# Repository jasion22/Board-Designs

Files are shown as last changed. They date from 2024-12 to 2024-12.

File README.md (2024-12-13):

# Gateway_Docking_Station
This project focuses on creating a gateway system that connects remote and host networks using a Raspberry Pi 3B+ and an RAK 833 (a LoRaWAN concentrator). This 

# Getting Started
- Make sure that you have a C1_Node_revb_v1.0.
- Raspberry Pi 3B+.
- RAK 833.

# Prerequisites
Board [Tested]

# Contributing
Instructions coming up soon.

# License
This project is licensed under the MIT License - see the LICENSE.md file for details

# Acknowledgments

# Changelog

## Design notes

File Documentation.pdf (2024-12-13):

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

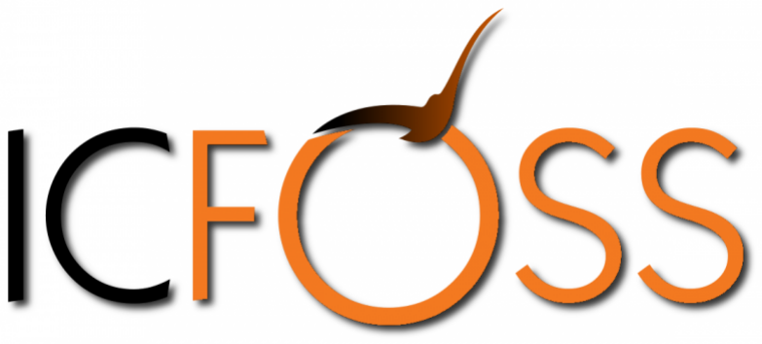
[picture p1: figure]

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

## 1. Summary

Any network has a boundary or a limit, so all communication placed within that network is conducted using the devices attached to it, including switches and routers. If a network node wants to communicate with a node/network that resides outsides of that network or autonomous system, the network will require the services of a gateway, which is familiar with the routing path of other remote networks.
The gateway (or default gateway) is implemented at the boundary of a network to manage all the data communication that is routed internally or externally from that network. Besides routing packets, gateways also possess information about the host network's internal paths and the learned path of dierent remote networks. If a network node wants to communicate with a foreign network, it will pass the data packet to the gateway, which then routes it to the destination using the best possible path.
The designed gateway docking station is implemented for easy installation process and provides voltage protection.

1

## 2. Problem denition and background

With the emergence of smart cities, smart communities and smart homes, the wireless technology has been greatly developed and applied for every research processes. Nowadays, the wireless methods are commonly used, such as GSM, GPRS, WIFI, ZigBee, etc.. LoRa (Long Range) is a spread spectrum modulation technique derived from chrip spread spectrum(CSS) technology and is the rst low-cost implementation of chirp spread spectrum for commercial usage. It was developed by Cycleo of Grenoble, France and acquired by Semtech in 2012, a founding member of the LoRa Alliance. Semtech's LoRa devices and wireless radio frequency technology (LoRa Technology) is a long range, low power wireless chipset that is used in a lot of Internet of Things (IoT) networks worldwide.
LoRaWAN is a protocol designed for creating large-scale public networks; the technology allows for sensors to talk to the internet without 3G or WiFi. Community crowdsourced projects, such as The Things Network, aim to provide access to this technology by deploying gateways globally that others can freely connect to.
We propose a mechanical water metering system through which we gather the readings by the help of reed switch on Low Power Mode and , thus consuming less power . This provides the device to work for years. The purpose is to provide a guide for people to create their own outdoor LoRaWAN Gateway using o-the-shelf components, rather than purchasing a commercial oering. Many of the components used in this design can be substituted for cheaper alternatives.

## 2.1 Literature review

The major issue based on previous versions of the gateways are

- Most of the gateways that are based on IoT does not provide any voltage protection method.
- Second the power is provided externally.
- Third there is no proper plug in design provided.

So by taking all the above mentioned issues we designed a board that works ne with any voltage issues and that can be used in any residential and commercial purpose. This is commonly

2

eective for large scale developments due to the extreme use of communication nowadays. This can provide the clear usage of data communication that can be accessed within a certain kilometers and could be used for many research purposes and equipments.

## 2.2 Reference solution

The main scope of the design is that the module can be retrotted to an enclosure. The proposed system also works in Low Power which provides a better method for energy consumption. The main objectives are:

- The proposed design provides with a crowbar circuit ie mainly used for voltage protection.
- The other challenge was to provide power without any external power plugins directly so by the use of POE (Power Over Ethernet) the board get sucient power and also a buck boost is provided.
- The board design provides with easy plugin connection for modules.

3

## 3. Design

The design of the project is basically the main task. Usually what's a gateway?. A gateway is a data communication device that provides a remote network with connectivity to a host network. A gateway device provides communication to a remote network or an autonomous system that is out of bounds for the host network nodes. Gateways serve as the entry and exit point of a network; all data routed inward or outward must rst pass through and communicate with the gateway in order to use routing paths. Generally, a router is congured to work as a gateway device in computer networks.
The device should be retrotted to the enclosure designed. For the basic needs the design was developed that can be easily plugged in.

## 3.1 Schematic Design

The schematic diagram represents the basic gateway design for Gateway Docking Station. 1 | 2 | 3 | 4 | 5 | 6
1 | 2 | 3 | 4 | 5 | 6 A

BC

D

A

BC

D Date: KiCad E.D.A. kicad 5.1.5+dfsg1-1 Size: A4 | Rev:
Id: 1/1 Title:

File: Daughter_Board.sch Sheet: / ¹ ² C5

10uF PWR_FLAG

+5V GND-power PWR_FLAG

1
2
3
J6Conn_01x03_Female | GND

PWR_FLAG

1 2 C8

10uF | SW1 SW_Push GND

+5V

1 2 C10

0.1uF

+5V

1 2 C4
47uF,5v D2 SMBJ5.0A
F1 MF-MSMF250/X | R1
1K | 0ER³

1 2 C9

0.1uF

1 2 C11

0.1uF GND

D3

BZG05C36-M

1
2

J3

5Vout | GND 1 VO 2 VI 3 U2 AMS1117-3.3

1 2 C3

# 0.1uF VIN 1 OUT 2 GND

3 FB 4 ON/OFF 5 U1
LM2596S-5

1
2

J4

3.3Vout +3.3V

+5V C6

0.1uf | 1 2 | C2
220uF,10V,AVX_TPSB107M010R0400 | F2 MF-MSMF250/X C7
0.1uf 1

10

2
3 | 4
5 | 6
7 | 8
9

J5 Conn_02x05_Odd_Even

1

10
11 | 12
13 | 14
15 | 16
17 | 18
19

2

20
21 | 22
23 | 24
25 | 26
27 | 28
29

3

30
31 | 32
33 | 34
35 | 36
37 | 38
39

4

40

5 | 6
7 | 8
9

J2 PI GPIO Header 1

2

3

J1
Barrel_Jack_Switch-Connector | Mechanical Key NC 1 | NC | 10 NC 11 | NC | 12 NC 13 | NC | 14 GND 15 | NC | 16 GND 17 | GND | 18 NC 19 | +3.3Vaux | 2 NC | 20 GND 21 | RESET | 22 NC 23 | +3.3Vaux | 24 NC 25 | GND | 26 GND 27 | NC | 28 GND 29 | NC 3 | NC | 30 NC 31 | NC | 32 NC 33 | GND | 34 GND 35 | NC | 36 GND 37 | NC | 38 +3.3Aux 39 | GND | 4 GND | 40 +3.3Aux 41 | NC | 42 GND 43 | NC | 44 PCIe_SCK 45 | NC | 46 PCIe_MISO 47 | NC | 48 PCIe_MOSI 49 | NC 5 | GND | 50 PCIe_CSN 51 | +3.3Vaux | 52 NC | 6 NC 7 | NC | 8 GND 9 | U3 RAK833_MPCIE

1 2

3 | Q1TIC106 GND | R² 100E

1 2 C14

0.1uF

1 2 C12

0.1uF

+3.3V D1 MBRS320T3G 1 2 | C1
470uF,40V,AVX_TPS | L1
47uH,L39 | GND

+3.3V

1 2 C13

0.1uF PCIe_MOSI PCIe_MOSI | PCIe_SCK

PCIe_SCK

PCIe_CSN

RESET PCIe_CSN1 | PCIe_MISO

PCIe_MISO

RESET PCIe_CSN1 PCIe_SCK | RESET PCIe_CSN
Vin | Vin PCIe_MOSI PCIe_MISO

Figure 3.1: Schematic Diagram

4

## 3.2 Layout Design

The layout design of the Gateway Docking Station.

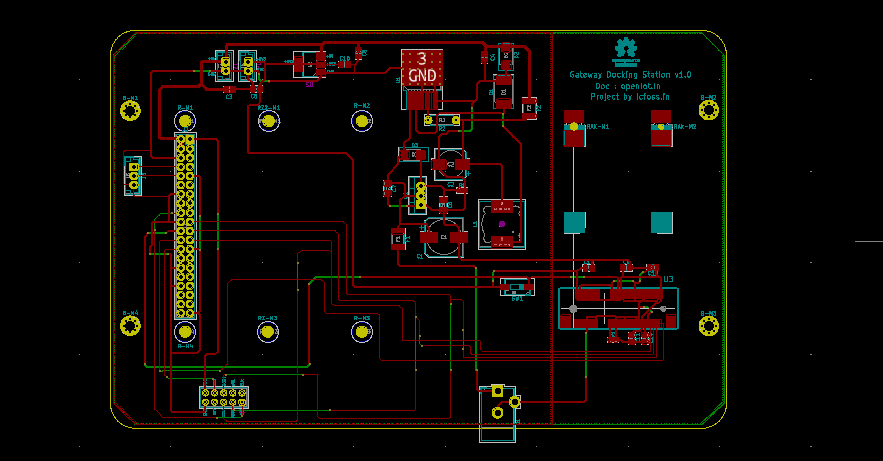
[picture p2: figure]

Figure 3.2: Layout Design without ll zone

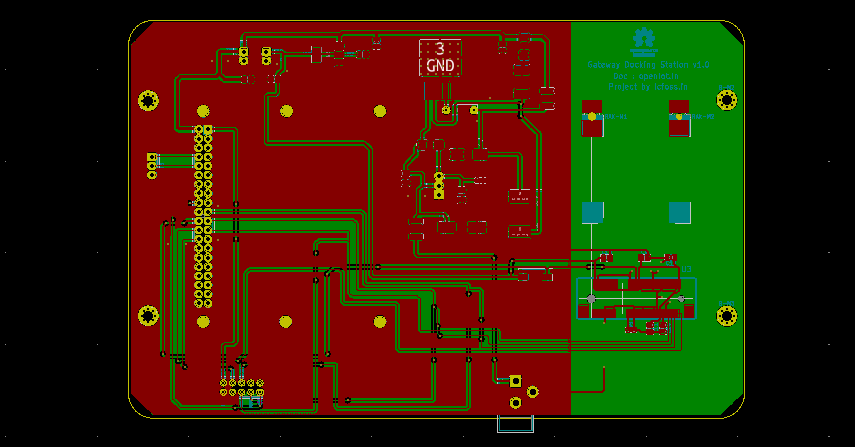
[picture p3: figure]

Figure 3.3: Layout Design with ll zone

5

## 4. Implementation

The proposed board is designed using a kicad an open software used for designing. The design consist of crowbar circuit from voltage protection with a buck boost which is essential for providind enough power for Raspberry pi and RaK 833. For the implementation of the gateway docking station the necessary circuits were developed. Tested each circuit seperately and all the necessary solutions were found out. Designed the schematic diagram and all the errors were cross checked and the layout was prepared. After several adjustments a board was developed and printed. All the components were assembled and checked.

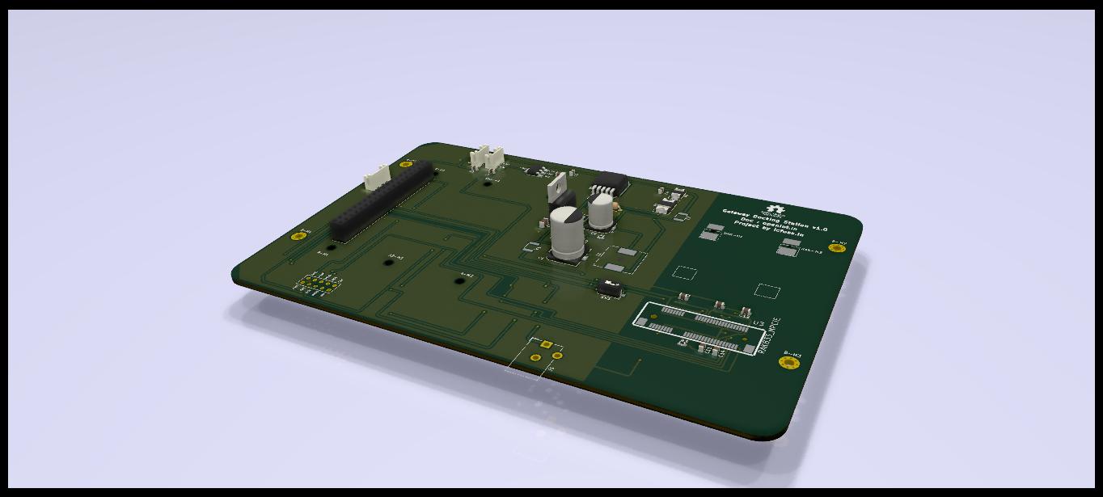
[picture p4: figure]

Figure 4.1: 3D Design of Gateway Docking Station

6

## 4.1 Hardware

The components that are used in the project are mentioned below.

1. Raspberry Pi 3b+

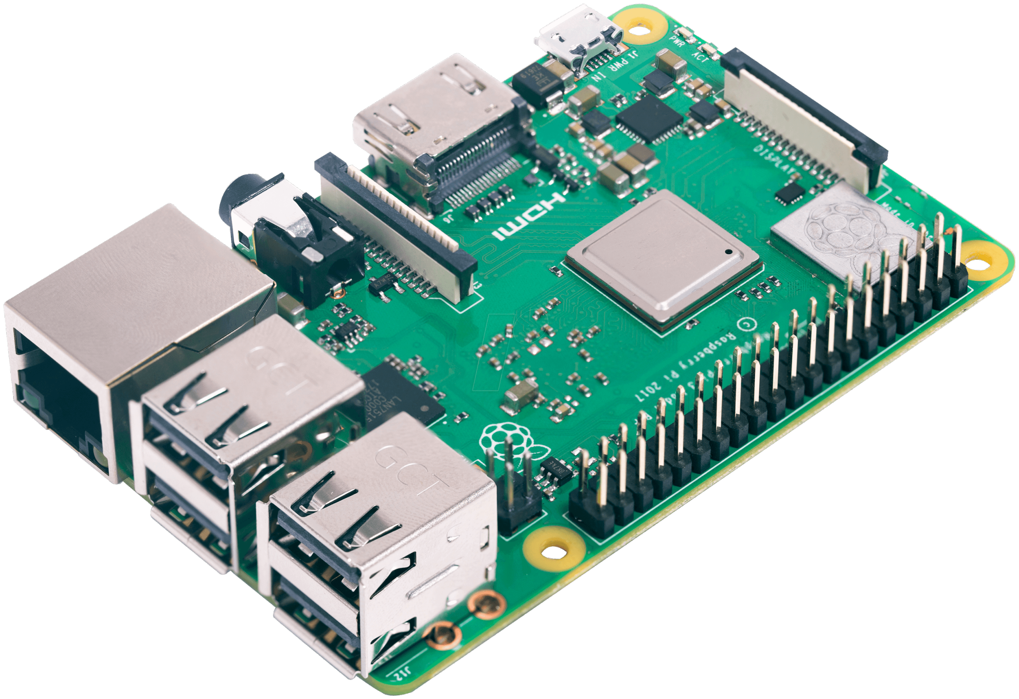
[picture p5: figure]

Figure 4.2: Raspberry Pi 3 Model B+

The Raspberry Pi 3 Model B+ is the latest product in the Raspberry Pi 3 range, boasting a 64-bit quad core processor running at 1.4 GHz, dual-band 2.4 GHz and 5 GHz wireless LAN, Bluetooth 4.2/BLE, faster Ethernet, and PoE capability via a separate PoE HATThe dual-band wireless LAN comes with modular compliance certication, allowing the board to be designed into end products with signicantly reduced wireless LAN compliance testing, improving both cost and time to market.

2. RAK 833

RAK833 is a fully-edged LoRaWAN

R concentrator module. It is very similar in function to the larger RAK831 module.The RAK wireless RAK83-SPI is a complete and cost eective LoRa gateway solution oering up to 10 programmable parallel demodulation paths. It's perfect for smart metering xed networks and IoT applications with up to 500 nodes per Km2 in moderately interfered environments.

| 7

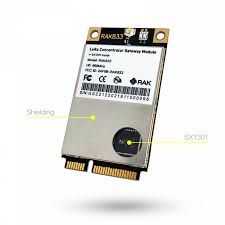
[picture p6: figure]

Figure 4.3: RAK 833

3. LM2596S-5

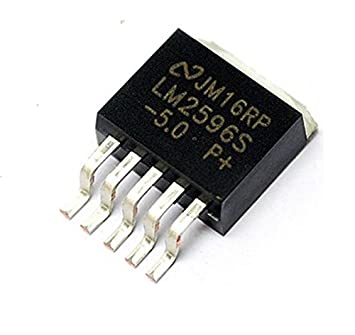
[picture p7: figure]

Figure 4.4: LM2596S-5

The LM2596 series of regulators are monolithic integrated circuits that provide all the active functions for a step-down(buck) switching regulator, capable of driving a 3-A load with excellent line and load regulation. These devices are available in xed output voltages of 3.3 V, 5 V, 12 V, and an adjustable output version.

8

## 4.2 How it Works

The Gateway Docking Station consist of a crowbar circuit, a buck boost and all the necessary plug in module headers and mini PCLE slot. The board is powered using an injector and basically works for Raspberry pi zero and Raspberry Pi 3 Model B+. A crowbar circuit is an electrical circuit used for preventing an overvoltage condition of a power supply unit from damaging the circuits attached to the power supply. It operates by putting a short circuit or low resistance path across the voltage output (Vo), quite like were one to drop a crowbar across the output terminals of the power supply.
The buckboost converter is a type of DC-to-DC converter that has an output voltage magnitude that is either greater than or less than the input voltage magnitude.The buck boost is used to provide essential power for the Raspberry pi. An AMS117 IC is used convert the 5V to 3.3V which is used to work the RAK 833. The RAK 833 is a concentrator module which is a complete and cost eective LoRa gateway.

## 4.3 Testing

The main and the conclusive part of the project is testing. Initially, all the components are tested and veried that they are working properly and identied the current consumption. After all the individual tests the components are integrated and checked that all the connections are proper.
The second phase is testing the circuit using a dot board. Next, testing the device performance under the lab condition and continuously monitor the output of the device and check if the device outputs are valid to our need.
The last phase is to deploy the device for the eld test, whether the device is performing under certain weather conditions. All the outputs are noted and compared with other similar devices. Finally, deploy the device for the implementation.

9

## 5. Results

For the testing of the device, several procedures are taken for accurate results. The product is designed for creating large-scale public networks, the technology allows for sensors to connect with the internet.

## 5.1 Test 1

From the initial state, the crowbar circuit is developed and tested. For the testing purpose several fuse were tested. Therfore 2A fuse is needed for the proper working of the circuit. Then next procedure was to nd out the total input current taken by the board. Therefore each modules input current is tested individually and also the eciency is calculated.
Total absolute input current = 2000+(2000*3) = 2600 mA
So it is approximately 2.6A. Therefore trace width is calculated using PCB calculator. All the necessary net classes width are gathered. After routing and all the procedures are completed a DRC check is done, whether there are errors or not. Then the board is cross checked and gerber les, pdf les are generated.
Finally, we test the device inside the lab condition and checked the performance. The test found to be successful, there is no problem regarding the device and also works ne using POE injector. After the lab test, the node is deployed for the eld test and again checked the performance. In both of the scenarios, the device performance was accurate without any problem and its output is compared with the commercial device and note the error percentage.

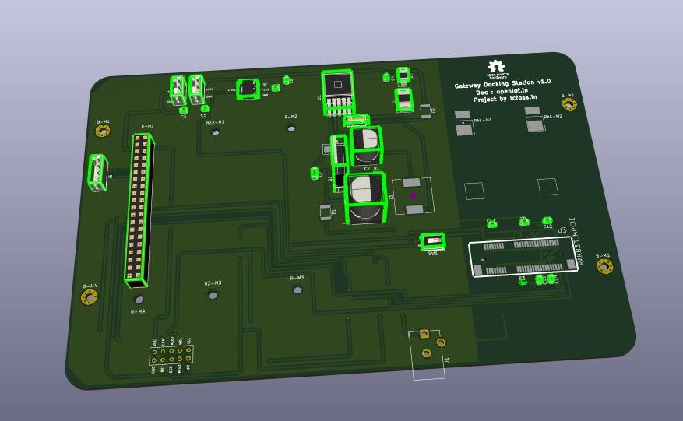
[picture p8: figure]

Figure 5.1: Gateway Docking Station V1.0

10

## 6. Conclusions

In this design, an IoT gateway for communicating dierent kinds of sensors was designed, consisting in a Raspberry Pi acting as a controller node, and RAK 833 concentrator and a web platform for monitor and control the network. The developed system so far, accomplishes the proposal features and purpose, giving the user the ability to access the environmental datas remotely. Nevertheless more tests to the system in multiple situations can be done in order to prove the eciency of the developed architecture.
In the future, we are planning to compare multiple communications protocols for each point of communication, or even oer a solution supporting multiple communication schemes. Furthermore, additional functionalities will be considered for the system, such as the possibility to create sets of rules directly from the platform and add Articial Intelligence or Machine Learning. At last, the focus will be towards a more secure system, with the implementation of encrypted communications and an SSL protocol and certicate on the webserver side.

11

## 7. Bibliography

- Kicad EDA
- www.youtube.com
- Several datasheets of the compponents and modules.

12

## Appendix A: Resources

Report the cong les of the software used (i.e. SU2 [?] and the mesher). Also attach to this report an archive with the mesh les, solutions and the reference solution data (e.g. data points of a Cp plot ...)

## Mesh conguration les

## SU2 conguration les

13
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

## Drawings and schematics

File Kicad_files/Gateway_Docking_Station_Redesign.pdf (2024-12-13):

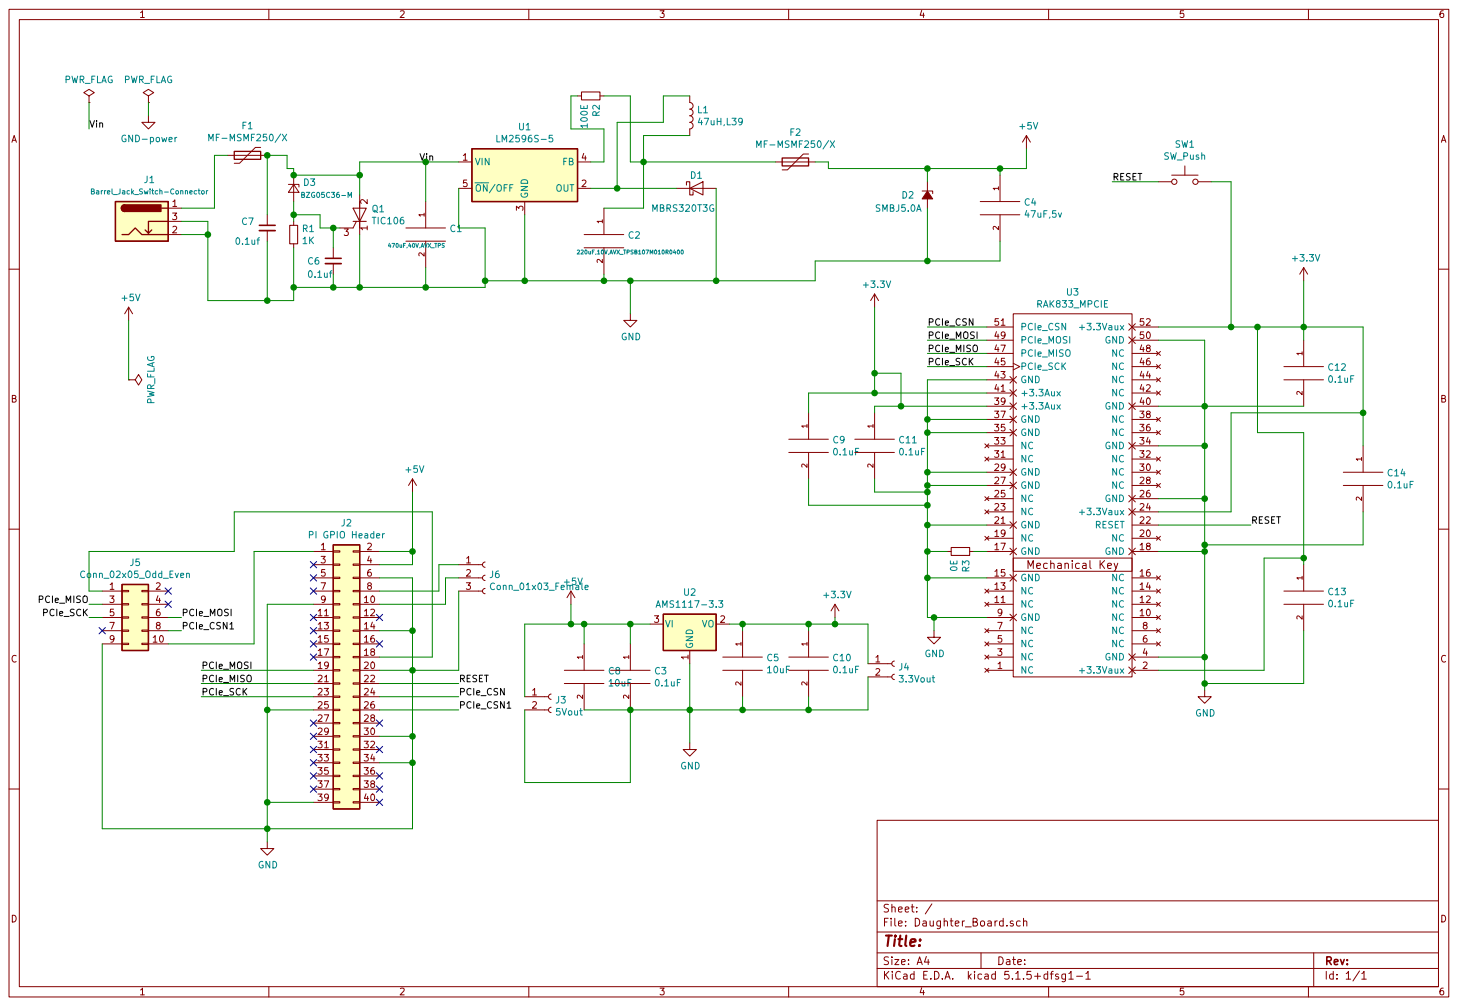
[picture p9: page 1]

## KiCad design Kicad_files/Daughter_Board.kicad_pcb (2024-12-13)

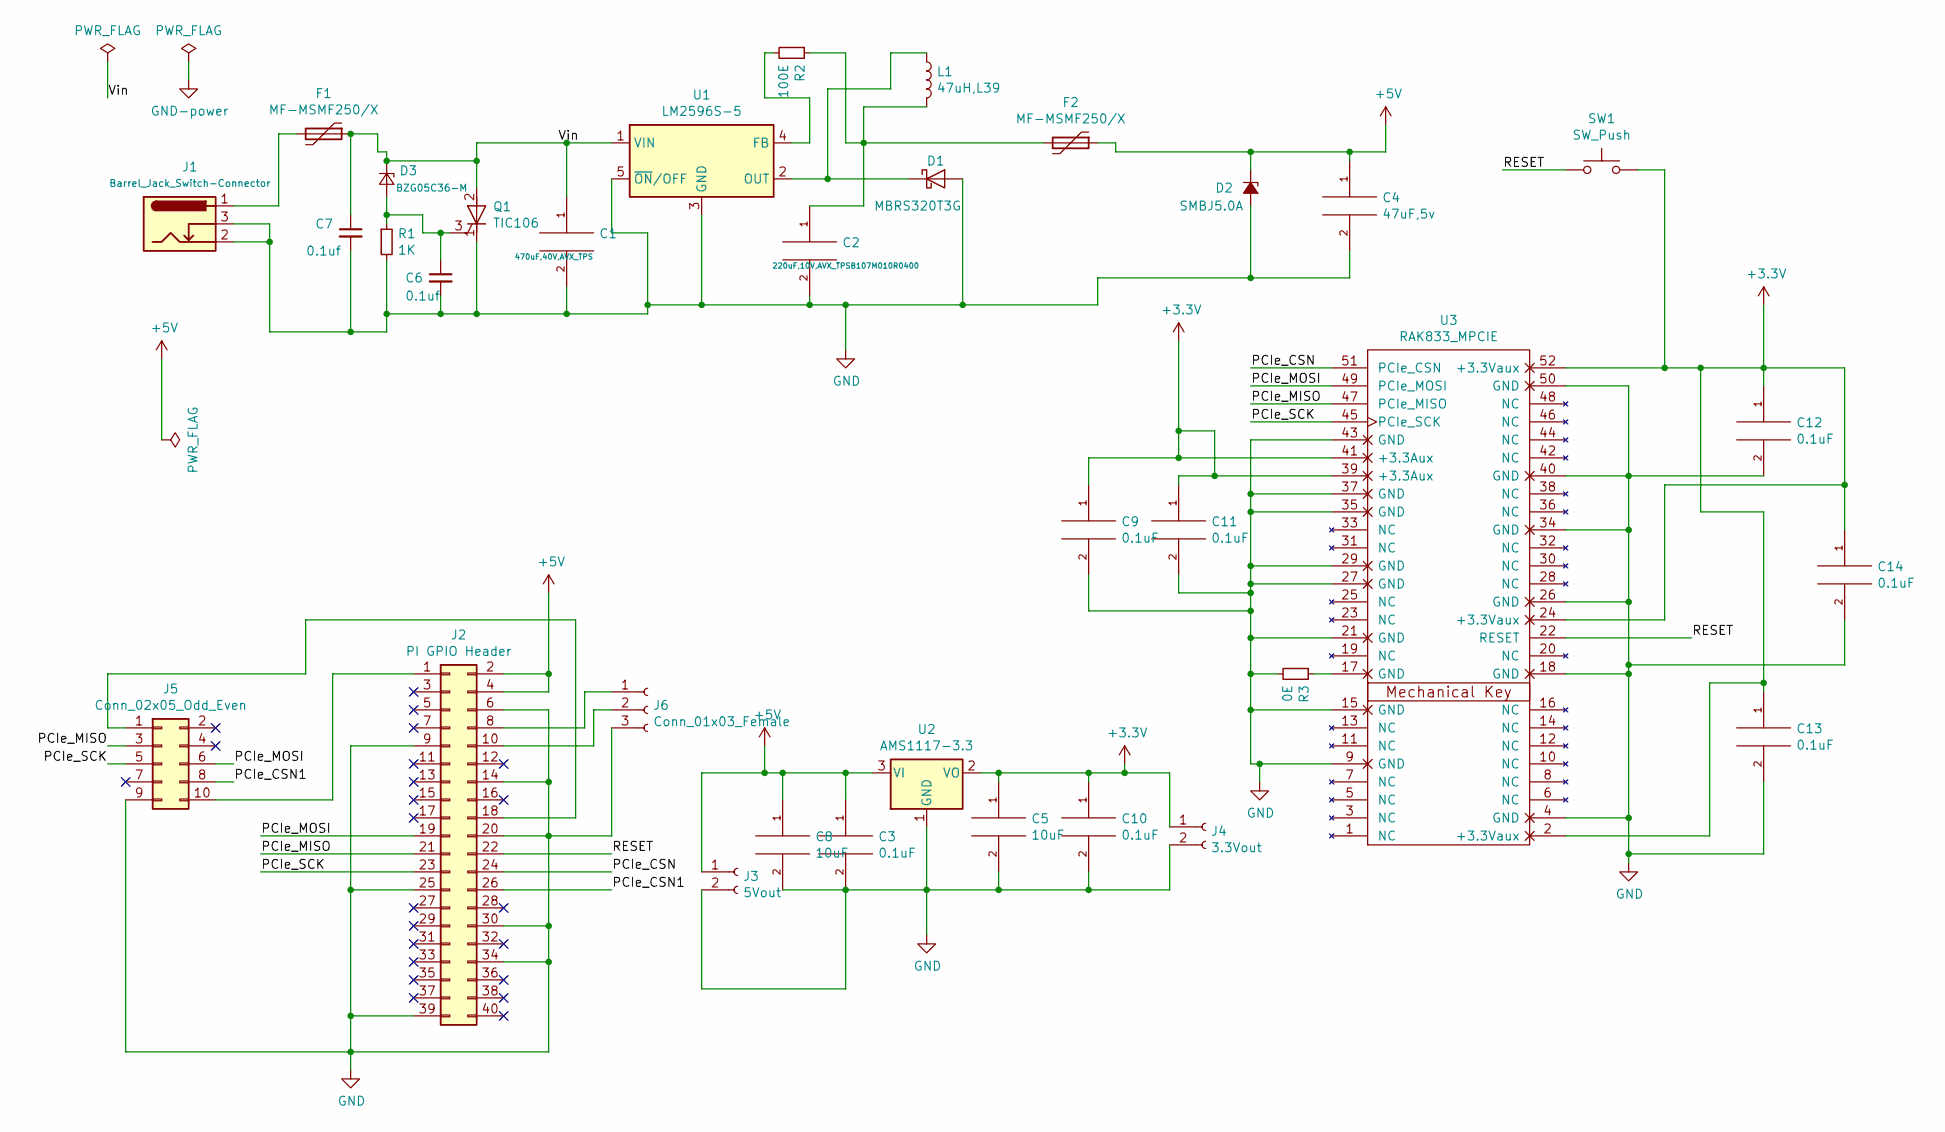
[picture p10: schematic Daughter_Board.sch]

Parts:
C1: 470uF,40V,AVX_TPS; CP_Elec_10x14.3
C2: 220uF,10V,AVX_TPSB107M010R0400; CP_Elec_8x10
C3, C9, C10, C11, C12, C13, C14: 0.1uF; C_0805_2012Metric
C4: 47uF,5v; C_0805_2012Metric
C5, C8: 10uF; C_0805_2012Metric
C6, C7: 0.1uf; C_1206_3216Metric
D1: MBRS320T3G; MBRS320T3G_Metric
D2: SMBJ5.0A; SMBJ5.0A_Metric
D3: BZG05C36-M; BZG05C36-M3-08_Metric
F1, F2: MF-MSMF250/X; Fuse_1812_4532Metric
J1: Barrel_Jack_Switch-Connector; BarrelJack_CUI_PJ-102AH_Horizontal
J2: PI GPIO Header; PinSocket_2x20_P2.54mm_Vertical
J3: 5Vout; JST_EH_B2B-EH-A_1x02_P2.50mm_Vertical
J4: 3.3Vout; JST_EH_B2B-EH-A_1x02_P2.50mm_Vertical
J5: Conn_02x05_Odd_Even; Samtec_HLE-105-02-xx-DV-TE_2x05_P2.54mm_Horizontal
J6: Conn_01x03_Female; JST_EH_B3B-EH-A_1x03_P2.50mm_Vertical
L1: 47uH,L39; L_12x12mm_H8mm
Q1: TIC106; TO-220-3_Vertical
R1: 1K; R_0603_1608Metric
R2: 100E; R_Axial_DIN0207_L6.3mm_D2.5mm_P7.62mm_Horizontal
R3: 0E; R_0603_1608Metric
SW1: SW_Push; SW_DIP_SPSTx01_Slide_6.7x4.1mm_W6.73mm_P2.54mm_LowProfile_J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
U1: LM2596S-5; TO-263-5_TabPin3
U2: AMS1117-3.3; SOT-223-3_TabPin2
U3: RAK833_MPCIE; mpcie-socket

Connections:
+3V3: C5.1, C9.1, C10.1, C11.1, C12.1, C13.1, C14.1, J4.1, SW1.2, U2.2 (VO), U3.2 (+3.3Vaux), U3.24 (+3.3Vaux), U3.39 (+3.3Aux), U3.41 (+3.3Aux), U3.52 (+3.3Vaux)
+5V: C3.1, C4.1, C8.1, D2.1 (K), F2.1, J2.2, J2.4, J3.1, U2.3 (VI)
/PCIe_CSN: J2.24, U3.51 (PCIe_CSN)
/PCIe_CSN1: J2.26, J5.8
/PCIe_MISO: J2.21, J5.3, U3.47 (PCIe_MISO)
/PCIe_MOSI: J2.19, J5.6, U3.49 (PCIe_MOSI)
/PCIe_SCK: J2.23, J5.5, U3.45 (PCIe_SCK)
/RESET: J2.22, SW1.1, U3.22 (RESET)
/Vin: C1.1, C7.1, D3.1 (K), F1.1, Q1.2 (A), U1.1 (VIN)
GND: C1.2, C2.2, C3.2, C4.2, C5.2, C6.2, C7.2, C8.2, C9.2, C10.2, C11.2, C12.2, C13.2, C14.2, D1.2 (A), D2.2 (A), J1.2, J1.3, J2.6, J2.9, J2.14, J2.20, J2.25, J2.30, J2.34, J2.39, J3.2, J4.2, J5.9, J6.3, Q1.1 (K), R1.2, R3.2, U1.3 (GND), U1.5 (~ON~/OFF), U2.1 (GND), U3.4 (GND), U3.9 (GND), U3.15 (GND), U3.18 (GND), U3.21 (GND), U3.26 (GND), U3.27 (GND), U3.29 (GND), U3.34 (GND), U3.35 (GND), U3.37 (GND), U3.40 (GND), U3.43 (GND), U3.50 (GND)
unnamed: C2.1, F2.2, L1.2, R2.1
unnamed: C6.1, D3.2 (A), Q1.3 (G), R1.1
unnamed: D1.1 (K), L1.1, U1.2 (OUT)
unnamed: F1.2, J1.1
unnamed: J2.1, J5.10
unnamed: J2.8, J6.1
unnamed: J2.10, J6.2
unnamed: J2.18, J5.1
unnamed: R2.2, U1.4 (FB)
unnamed: R3.1, U3.17 (GND)

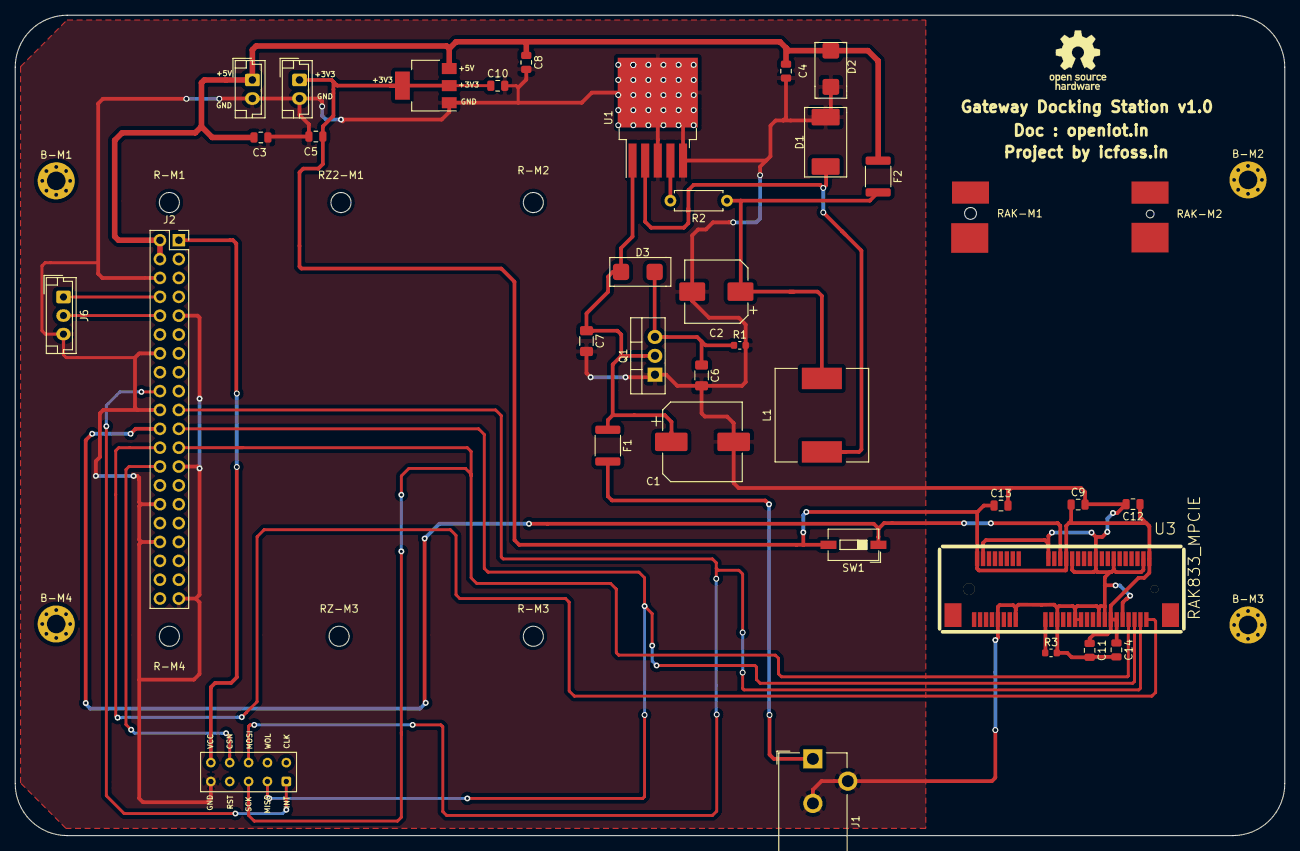
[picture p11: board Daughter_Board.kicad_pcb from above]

Board: 2 copper layers, 171.0 x 110.5 mm, 46 parts (0 on the bottom side), 20 nets.

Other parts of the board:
B-M1, B-M2, B-M3, B-M4: MountingHole_2.5mm_Pad_Via
R-M1, R-M2, R-M3, R-M4: MountingHole_2.7mm_M2.5
RAK-M1, RAK-M2: MountingHole_2.1mm
RZ2-M1: MountingHole_2.7mm_M2.5
RZ-M3: MountingHole_2.7mm_M2.5
